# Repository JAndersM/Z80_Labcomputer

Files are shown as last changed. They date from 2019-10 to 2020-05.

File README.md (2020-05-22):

# Z80_Labcomputer

A computerproject based on the Z80 CPU.

## Dator
Motherboard with Z80, 8 kB ROM and 32 kB SRAM, IO ports, Bus ports etc.
* Schema, PCB designed
* Produced and tested. OK so far...

## cpukontroll
Clock, Reset etc.
* Schema, PCB design

## display
7x4-segment display and IO-connections to adress 0-3
* Schema PCB design

## tangentbord
Hex values input keyboard
* Schema, PCB design
Needs redesign

## EEPROMprogrammer
Arduino code and design for an Arduino Nano (or similar) based EEPROMprogrammer
* Schema, PCB design
Connected to the computer using BUSRQ to facilitate programming without removing ROM.

## simulering
Python simulation of the z80 cpu and the computer
* Inkludes 7x4 display
Many opcodes not simulated yet

## fastplatta
Holder for the Dator PCB
* 3D printed and tested

## Used software:
KiCad, FreeCAD, Python, Arduino IDE

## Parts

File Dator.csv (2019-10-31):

Reference | Quantity | Value | Footprint | Datasheet | Comment
C2 C3 C5 C6 C7 C1 C8 | 7 | 47n | Capacitor_THT:C_Disc_D3.0mm_W1.6mm_P2.50mm | ~
C4 | 1 | 22u | Capacitor_THT:C_Radial_D5.0mm_H11.0mm_P2.00mm | ~
D1 | 1 | LED | LED_THT:LED_D3.0mm | ~ | Green low current
H1 H2 | 2 | MountingHole | MountingHole:MountingHole_2.2mm_M2 | ~
J1 | 1 | CPU Control | Connector_PinHeader_2.54mm:PinHeader_1x05_P2.54mm_Vertical | ~
J2 | 1 | USB_B | Connector_USB:USB_B_OST_USB-B1HSxx_Horizontal | ~
J3 | 1 | IO Port | Connector_PinHeader_2.54mm:PinHeader_1x24_P2.54mm_Vertical | ~
J4 | 1 | Add Sig | Connector_PinSocket_2.54mm:PinSocket_1x05_P2.54mm_Vertical | ~
J5 | 1 | Address Bus | Connector_PinSocket_2.54mm:PinSocket_1x16_P2.54mm_Vertical | ~
J6 | 1 | Data Bus | Connector_PinSocket_2.54mm:PinSocket_1x08_P2.54mm_Vertical | ~
J7 | 1 | BUS NMI | Connector_PinSocket_2.54mm:PinSocket_1x05_P2.54mm_Vertical | ~
R1 | 1 | 1k5 | Resistor_THT:R_Axial_DIN0207_L6.3mm_D2.5mm_P7.62mm_Horizontal | ~
R2 R3 | 2 | 10k | Resistor_THT:R_Axial_DIN0207_L6.3mm_D2.5mm_P7.62mm_Horizontal | ~
U1 | 1 | 4002 | Package_DIP:DIP-14_W7.62mm | http://www.intersil.com/content/dam/Intersil/documents/cd40/cd4000bms-01bms-02bms-25bms.pdf
U2 U8 | 2 | 4071 | Package_DIP:DIP-14_W7.62mm | http://www.intersil.com/content/dam/Intersil/documents/cd40/cd4071bms-72bms-75bms.pdf
U3 | 1 | Z80CPU | Package_DIP:DIP-40_W15.24mm_Socket | www.zilog.com/manage_directlink.php?filepath=docs/z80/um0080
U4 | 1 | 74LS283 | Package_DIP:DIP-16_W7.62mm | http://www.ti.com/lit/gpn/sn74LS283
U5 | 1 | AT28C64B15PU | Package_DIP:DIP-28_W15.24mm_Socket
U6 | 1 | HM62256LP-8 | Package_DIP:DIP-28_W15.24mm_Socket
U7 | 1 | 74HC245 | Package_DIP:DIP-20_W7.62mm | http://www.ti.com/lit/gpn/sn74HC245

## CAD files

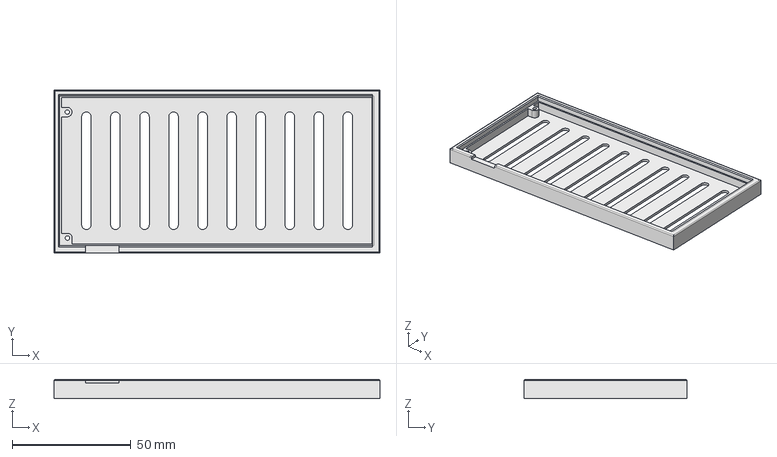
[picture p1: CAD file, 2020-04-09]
fastplatta/platta.FCStd
137.2 x 68.6 x 8.00 mm

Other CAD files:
fastplatta/platta.stl

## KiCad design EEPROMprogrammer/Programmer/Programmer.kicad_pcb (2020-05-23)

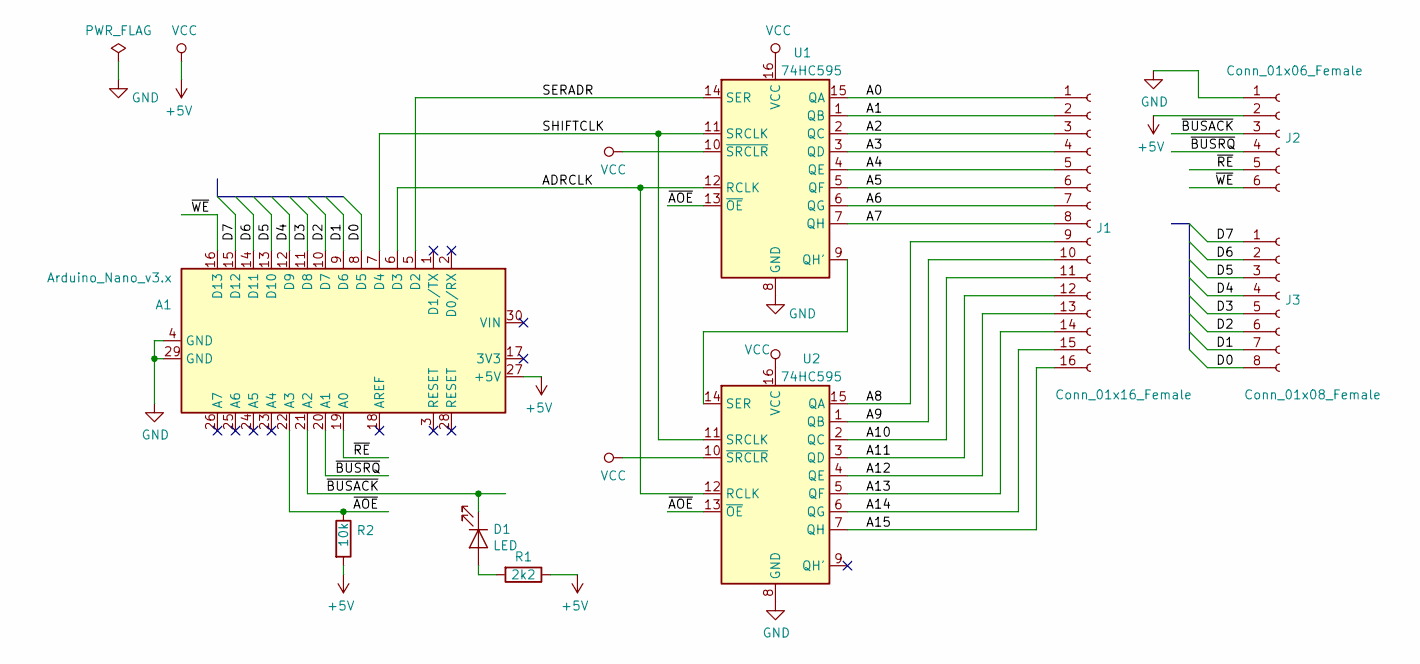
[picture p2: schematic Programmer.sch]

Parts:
A1: Arduino_Nano_v3.x; Arduino_Nano
D1: LED; LED_D3.0mm
J1: Conn_01x16_Female; PinSocket_1x16_P2.54mm_Vertical
J2: Conn_01x06_Female; PinSocket_1x06_P2.54mm_Vertical
J3: Conn_01x08_Female; PinSocket_1x08_P2.54mm_Vertical
R1: 2k2; R_Axial_DIN0207_L6.3mm_D2.5mm_P7.62mm_Horizontal
R2: 10k; R_Axial_DIN0207_L6.3mm_D2.5mm_P7.62mm_Horizontal
U1, U2: 74HC595; DIP-16_W7.62mm

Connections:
+5V: A1.27 (+5V), J2.2, R1.1, R2.2, U1.10 (~SRCLR), U1.16 (VCC), U2.10 (~SRCLR), U2.16 (VCC)
/A0: J1.1, U1.15 (QA)
/A1: J1.2, U1.1 (QB)
/A2: J1.3, U1.2 (QC)
/A3: J1.4, U1.3 (QD)
/A4: J1.5, U1.4 (QE)
/A5: J1.6, U1.5 (QF)
/A6: J1.7, U1.6 (QG)
/A7: J1.8, U1.7 (QH)
/A8: J1.9, U2.15 (QA)
/A9: J1.10, U2.1 (QB)
/A10: J1.11, U2.2 (QC)
/A11: J1.12, U2.3 (QD)
/A12: J1.13, U2.4 (QE)
/A13: J1.14, U2.5 (QF)
/A14: J1.15, U2.6 (QG)
/A15: J1.16, U2.7 (QH)
/ADRCLK: A1.6 (D3), U1.12 (RCLK), U2.12 (RCLK)
/D0: A1.8 (D5), J3.8
/D1: A1.9 (D6), J3.7
/D2: A1.10 (D7), J3.6
/D3: A1.11 (D8), J3.5
/D4: A1.12 (D9), J3.4
/D5: A1.13 (D10), J3.3
/D6: A1.14 (D11), J3.2
/D7: A1.15 (D12), J3.1
/SERADR: A1.5 (D2), U1.14 (SER)
/SHIFTCLK: A1.7 (D4), U1.11 (SRCLK), U2.11 (SRCLK)
/~AOE: A1.22 (A3), R2.1, U1.13 (~OE), U2.13 (~OE)
/~BUSACK: A1.21 (A2), D1.1 (K), J2.3
/~BUSRQ: A1.20 (A1), J2.4
/~RE: A1.19 (A0), J2.5
/~WE: A1.16 (D13), J2.6
GND: A1.4 (GND), A1.29 (GND), J2.1, U1.8 (GND), U2.8 (GND)
unnamed: D1.2 (A), R1.2
unnamed: U1.9 (QH'), U2.14 (SER)

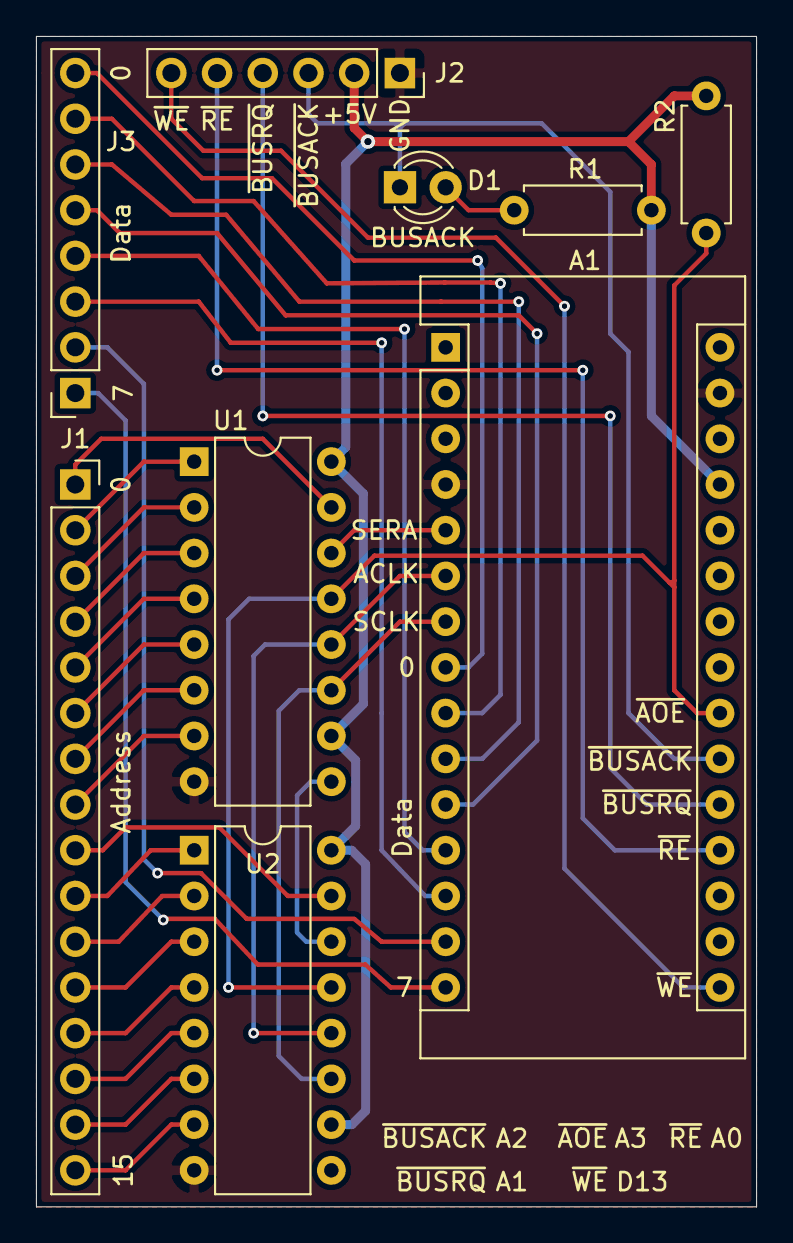
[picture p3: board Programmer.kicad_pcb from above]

Board: 2 copper layers, 40.0 x 65.0 mm, 9 parts (0 on the bottom side), 36 nets.

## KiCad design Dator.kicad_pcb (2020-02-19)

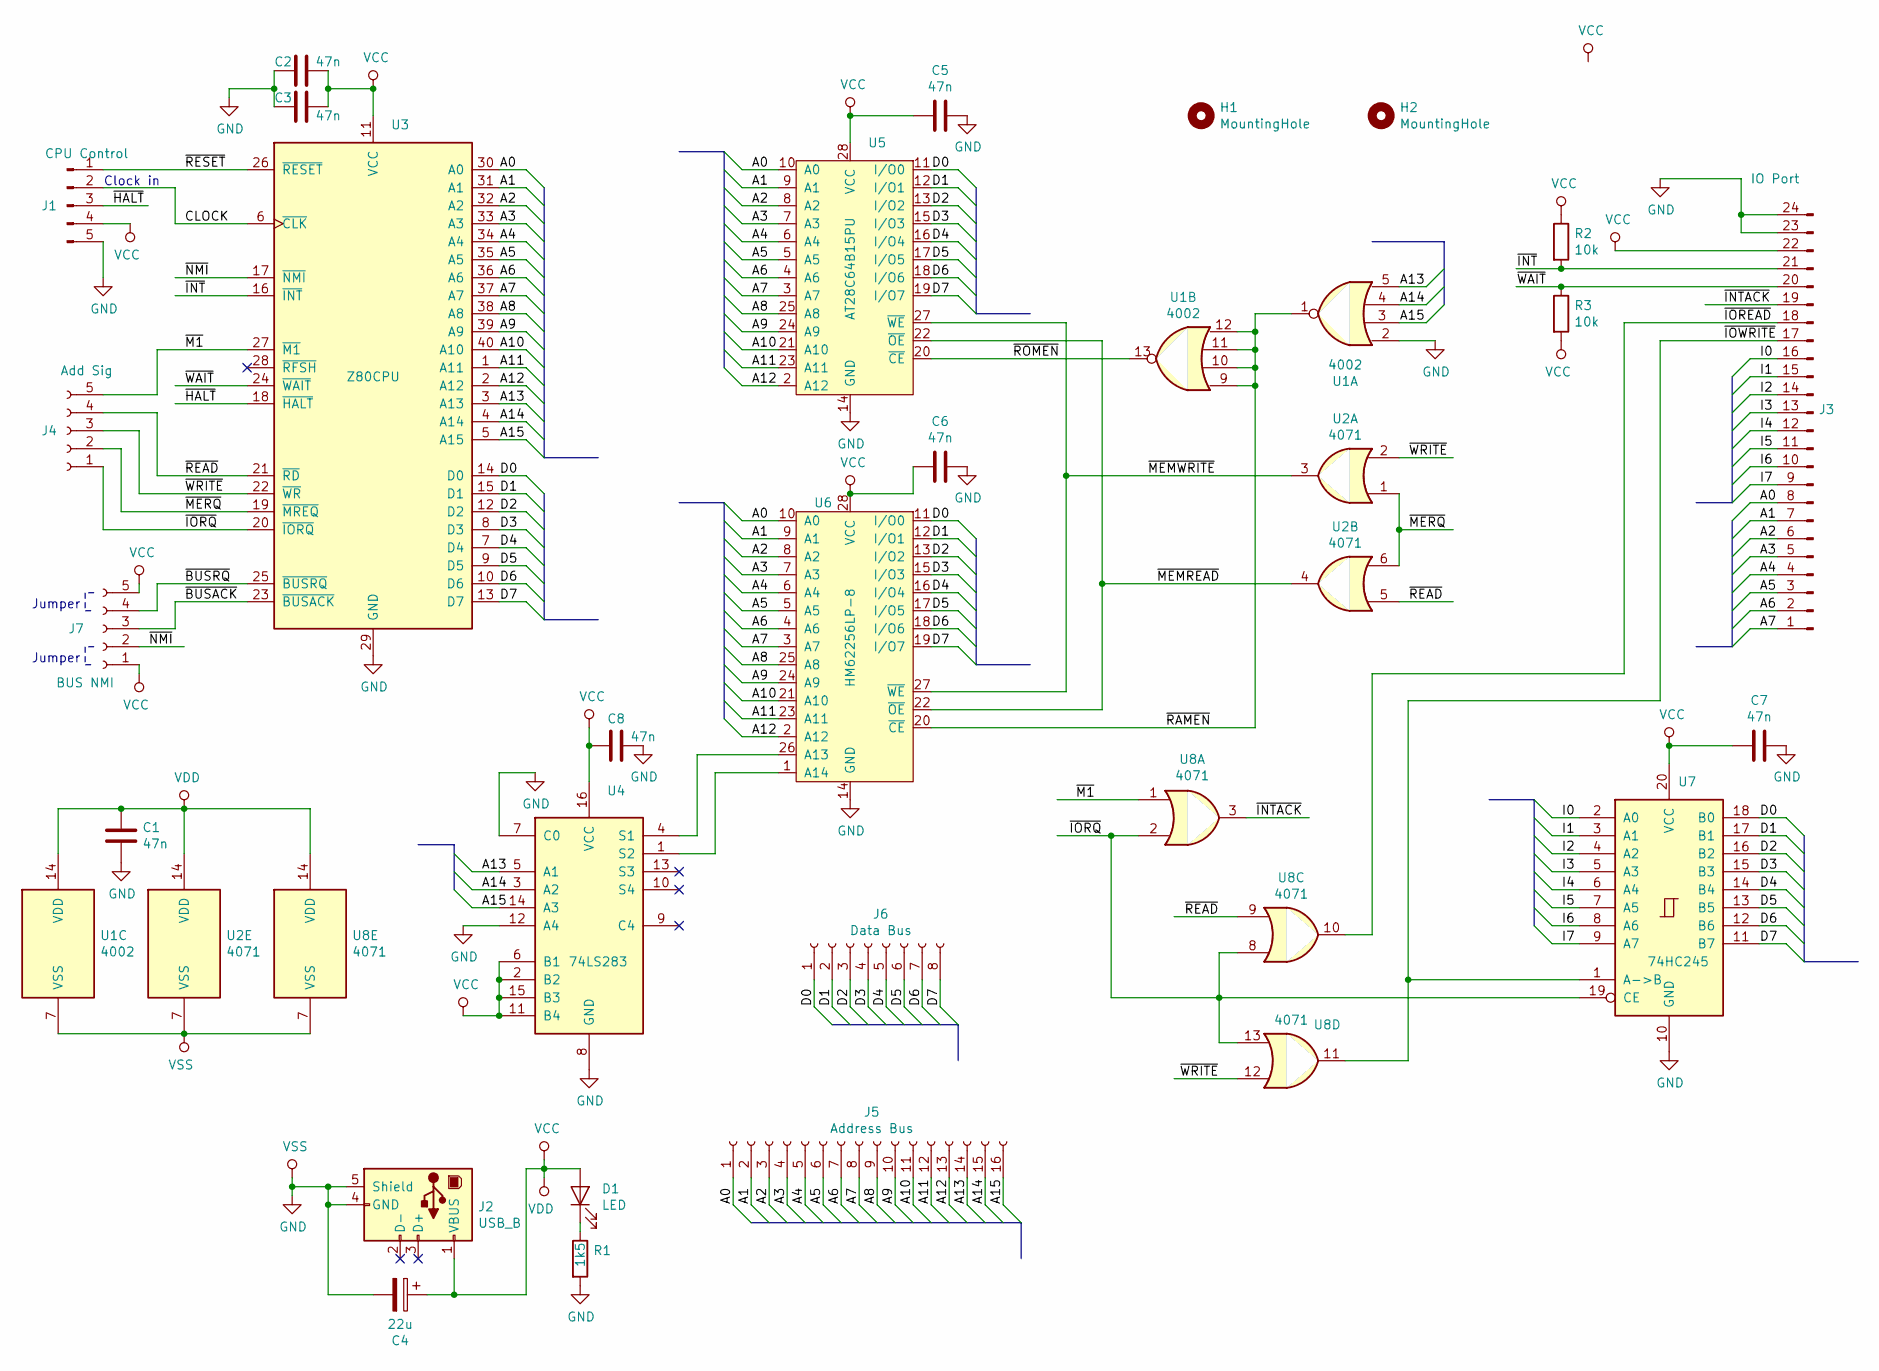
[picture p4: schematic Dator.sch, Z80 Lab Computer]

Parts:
C1, C2, C3, C5, C6, C7, C8: 47n; C_Disc_D3.0mm_W1.6mm_P2.50mm
C4: 22u; C_Radial_D5.0mm_H11.0mm_P2.00mm
D1: LED; LED_D3.0mm
H1, H2: MountingHole; MountingHole_2.2mm_M2
J1: CPU Control; PinHeader_1x05_P2.54mm_Vertical
J2: USB_B; USB_B_OST_USB-B1HSxx_Horizontal
J3: IO Port; PinHeader_1x24_P2.54mm_Vertical
J4: Add Sig; PinSocket_1x05_P2.54mm_Vertical
J5: Address Bus; PinSocket_1x16_P2.54mm_Vertical
J6: Data Bus; PinSocket_1x08_P2.54mm_Vertical
J7: BUS NMI; PinSocket_1x05_P2.54mm_Vertical
R1: 1k5; R_Axial_DIN0207_L6.3mm_D2.5mm_P7.62mm_Horizontal
R2, R3: 10k; R_Axial_DIN0207_L6.3mm_D2.5mm_P7.62mm_Horizontal
U1: 4002; DIP-14_W7.62mm
U2, U8: 4071; DIP-14_W7.62mm
U3: Z80CPU; DIP-40_W15.24mm_Socket
U4: 74LS283; DIP-16_W7.62mm
U5: AT28C64B15PU; DIP-28_W15.24mm_Socket
U6: HM62256LP-8; DIP-28_W15.24mm_Socket
U7: 74HC245; DIP-20_W7.62mm

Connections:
/A0: J3.8, J5.1, U3.30 (A0), U5.10 (A0), U6.10 (A0)
/A1: J3.7, J5.2, U3.31 (A1), U5.9 (A1), U6.9 (A1)
/A2: J3.6, J5.3, U3.32 (A2), U5.8 (A2), U6.8 (A2)
/A3: J3.5, J5.4, U3.33 (A3), U5.7 (A3), U6.7 (A3)
/A4: J3.4, J5.5, U3.34 (A4), U5.6 (A4), U6.6 (A4)
/A5: J3.3, J5.6, U3.35 (A5), U5.5 (A5), U6.5 (A5)
/A6: J3.2, J5.7, U3.36 (A6), U5.4 (A6), U6.4 (A6)
/A7: J3.1, J5.8, U3.37 (A7), U5.3 (A7), U6.3 (A7)
/A8: J5.9, U3.38 (A8), U5.25 (A8), U6.25 (A8)
/A9: J5.10, U3.39 (A9), U5.24 (A9), U6.24 (A9)
/A10: J5.11, U3.40 (A10), U5.21 (A10), U6.21 (A10)
/A11: J5.12, U3.1 (A11), U5.23 (A11), U6.23 (A11)
/A12: J5.13, U3.2 (A12), U5.2 (A12), U6.2 (A12)
/A13: J5.14, U1.5, U3.3 (A13), U4.5 (A1)
/A14: J5.15, U1.4, U3.4 (A14), U4.3 (A2)
/A15: J5.16, U1.3, U3.5 (A15), U4.14 (A3)
/CLOCK: J1.2, U3.6 (~CLK~)
/D0: J6.1, U3.14 (D0), U5.11 (I/O0), U6.11 (I/O0), U7.18 (B0)
/D1: J6.2, U3.15 (D1), U5.12 (I/O1), U6.12 (I/O1), U7.17 (B1)
/D2: J6.3, U3.12 (D2), U5.13 (I/O2), U6.13 (I/O2), U7.16 (B2)
/D3: J6.4, U3.8 (D3), U5.15 (I/O3), U6.15 (I/O3), U7.15 (B3)
/D4: J6.5, U3.7 (D4), U5.16 (I/O4), U6.16 (I/O4), U7.14 (B4)
/D5: J6.6, U3.9 (D5), U5.17 (I/O5), U6.17 (I/O5), U7.13 (B5)
/D6: J6.7, U3.10 (D6), U5.18 (I/O6), U6.18 (I/O6), U7.12 (B6)
/D7: J6.8, U3.13 (D7), U5.19 (I/O7), U6.19 (I/O7), U7.11 (B7)
/I0: J3.16, U7.2 (A0)
/I1: J3.15, U7.3 (A1)
/I2: J3.14, U7.4 (A2)
/I3: J3.13, U7.5 (A3)
/I4: J3.12, U7.6 (A4)
/I5: J3.11, U7.7 (A5)
/I6: J3.10, U7.8 (A6)
/I7: J3.9, U7.9 (A7)
/~BUSACK: J7.3, U3.23 (~BUSACK~)
/~BUSRQ: J7.4, U3.25 (~BUSRQ~)
/~HALT: J1.3, U3.18 (~HALT~)
/~INT: J3.21, R2.2, U3.16 (~INT~)
/~INTACK: J3.19, U8.3
/~IOREAD: J3.18, U8.10
/~IORQ: J4.1, U3.20 (~IORQ~), U7.19 (CE), U8.2, U8.8, U8.13
/~IOWRITE: J3.17, U7.1 (A->B), U8.11
/~M1: J4.5, U3.27 (~M1~), U8.1
/~MEMREAD: U2.4, U5.22 (~OE), U6.22 (~OE)
/~MEMWRITE: U2.3, U5.27 (~WE), U6.27 (~WE)
/~MERQ: J4.2, U2.1, U2.6, U3.19 (~MREQ~)
/~NMI: J7.2, U3.17 (~NMI~)
/~RAMEN: U1.1, U1.9, U1.10, U1.11, U1.12, U6.20 (~CE)
/~READ: J4.4, U2.5, U3.21 (~RD~), U8.9
/~RESET: J1.1, U3.26 (~RESET~)
/~ROMEN: U1.13, U5.20 (~CE)
/~WAIT: J3.20, R3.1, U3.24 (~WAIT~)
/~WRITE: J4.3, U2.2, U3.22 (~WR~), U8.12
GND: C1.2, C2.2, C3.2, C4.2, C5.1, C6.1, C7.1, C8.1, J1.5, J2.4 (GND), J2.5 (Shield), J3.23, J3.24, R1.2, U1.2, U1.7 (VSS), U2.7 (VSS), U3.29 (GND), U4.7 (C0), U4.8 (GND), U4.12 (A4), U5.14 (GND), U6.14 (GND), U7.10 (GND), U8.7 (VSS)
unnamed: D1.1 (K), R1.1
unnamed: U4.1 (S2), U6.1 (A14)
unnamed: U4.4 (S1), U6.26 (A13)
VCC: C1.1, C2.1, C3.1, C4.1, C5.2, C6.2, C7.2, C8.2, D1.2 (A), J1.4, J2.1 (VBUS), J3.22, J7.1, J7.5, R2.1, R3.2, U1.14 (VDD), U2.14 (VDD), U3.11 (VCC), U4.2 (B2), U4.6 (B1), U4.11 (B4), U4.15 (B3), U4.16 (VCC), U5.28 (VCC), U6.28 (VCC), U7.20 (VCC), U8.14 (VDD)

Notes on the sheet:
Clock in
Jumper

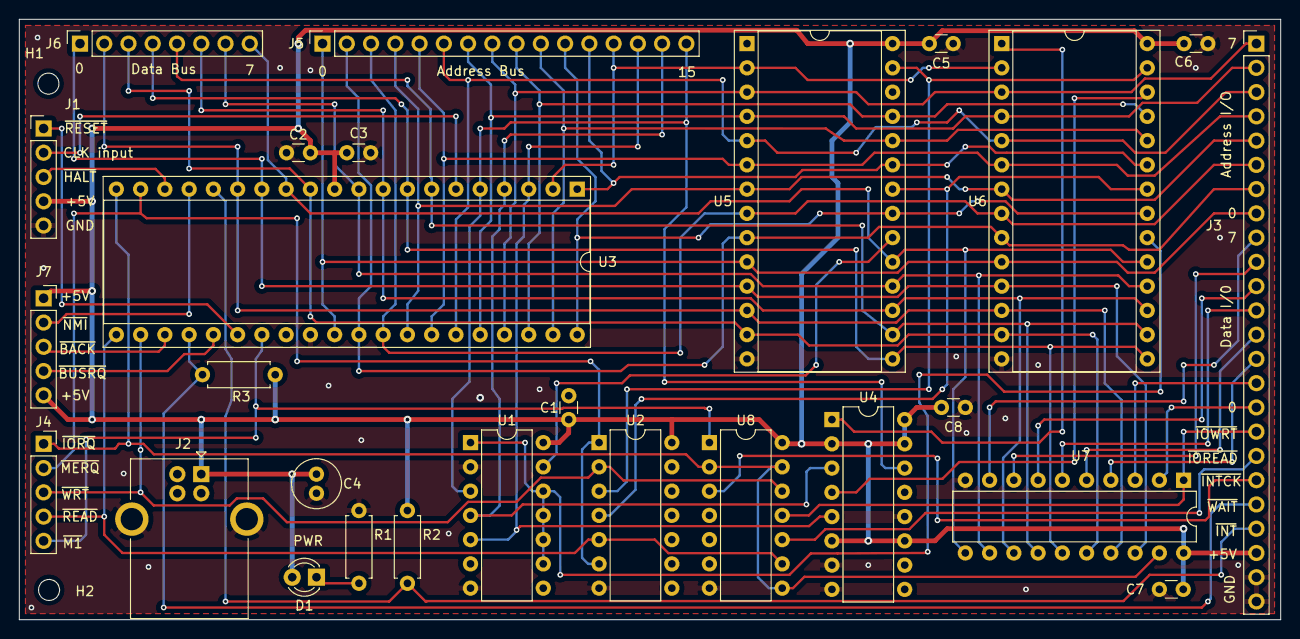
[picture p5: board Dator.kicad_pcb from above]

Board: 2 copper layers, 132.1 x 62.9 mm, 29 parts (0 on the bottom side), 57 nets.

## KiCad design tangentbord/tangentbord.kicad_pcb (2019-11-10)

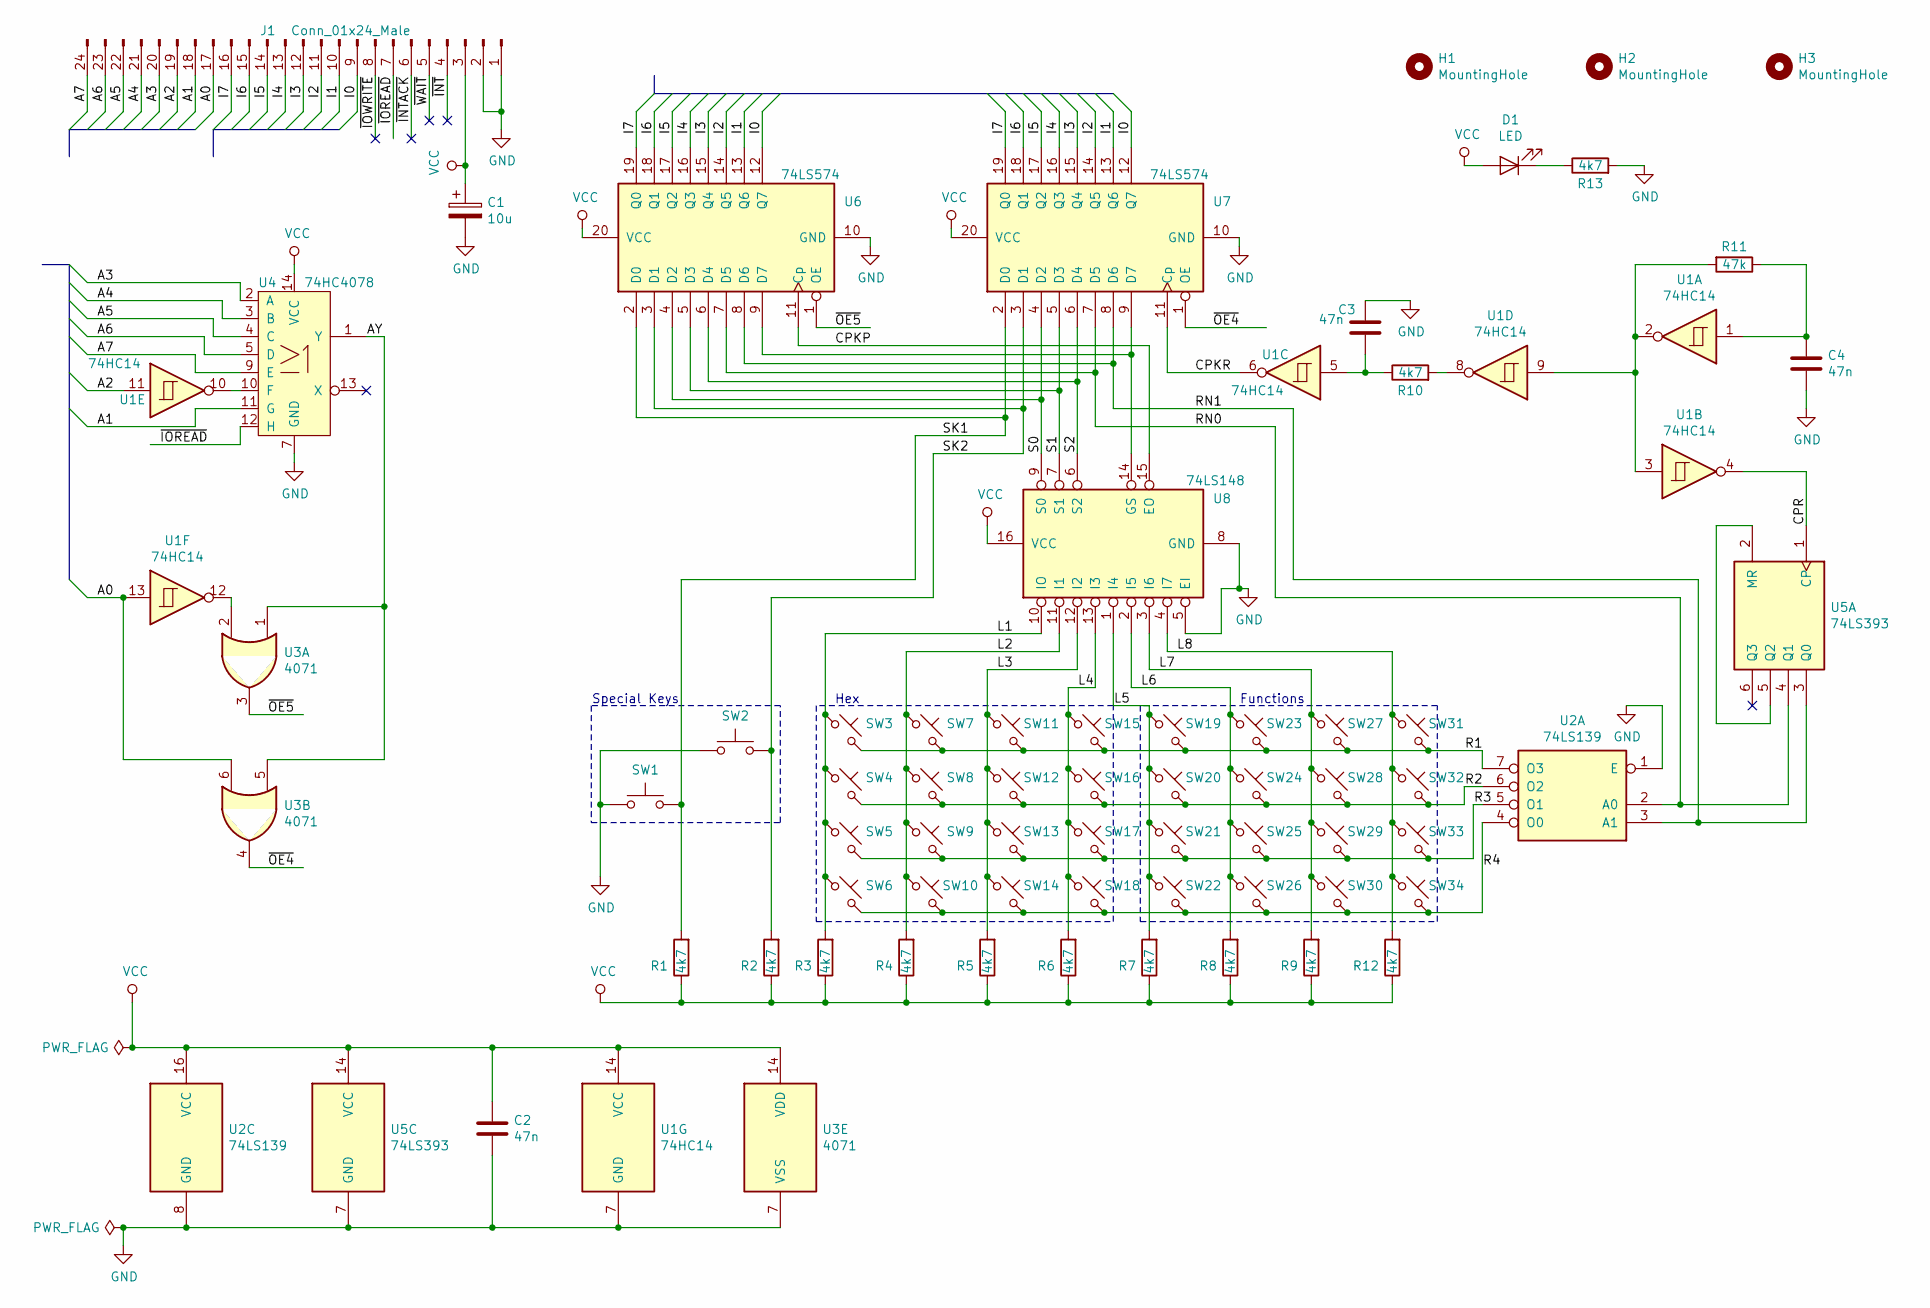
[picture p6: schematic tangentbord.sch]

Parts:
C1: 10u; CP_Radial_D5.0mm_P2.00mm
C2, C3, C4: 47n; C_Disc_D3.0mm_W2.0mm_P2.50mm
D1: LED; LED_D3.0mm
H1, H2, H3: MountingHole; MountingHole_2.2mm_M2
J1: Conn_01x24_Male; PinHeader_1x24_P2.54mm_Vertical
R1, R2, R3, R4, R5, R6, R7, R8, R9, R10, R12, R13: 4k7; R_Axial_DIN0207_L6.3mm_D2.5mm_P7.62mm_Horizontal
R11: 47k; R_Axial_DIN0207_L6.3mm_D2.5mm_P7.62mm_Horizontal
SW1, SW2: SW_Push; SW_PUSH_6mm
SW3, SW4, SW5, SW6, SW7, SW8, SW9, SW10, SW11, SW12, SW13, SW14, SW15, SW16, SW17, SW18, SW19, SW20, SW21, SW22, SW23, SW24, SW25, SW26, SW27, SW28, SW29, SW30, SW31, SW32, SW33, SW34: SW_Push_45deg; SW_PUSH_6mm
U1: 74HC14; DIP-14_W7.62mm
U2: 74LS139; DIP-16_W7.62mm
U3: 4071; DIP-14_W7.62mm
U4: 74HC4078; DIP-14_W7.62mm
U5: 74LS393; DIP-14_W7.62mm
U6, U7: 74LS574; DIP-20_W7.62mm
U8: 74LS148; DIP-16_W7.62mm

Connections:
/A0: J1.17, U1.13, U3.6
/A1: J1.18, U4.11 (G)
/A2: J1.19, U1.11
/A3: J1.20, U4.2 (A)
/A4: J1.21, U4.3 (B)
/A5: J1.22, U4.4 (C)
/A6: J1.23, U4.5 (D)
/A7: J1.24, U4.9 (E)
/AY: U3.1, U3.5, U4.1 (Y)
/CPKP: U6.11 (Cp), U8.15 (EO)
/CPKR: U1.6, U7.11 (Cp)
/CPR: U1.4, U5.1 (CP)
/I0: J1.9, U6.12 (Q7), U7.12 (Q7)
/I1: J1.10, U6.13 (Q6), U7.13 (Q6)
/I2: J1.11, U6.14 (Q5), U7.14 (Q5)
/I3: J1.12, U6.15 (Q4), U7.15 (Q4)
/I4: J1.13, U6.16 (Q3), U7.16 (Q3)
/I5: J1.14, U6.17 (Q2), U7.17 (Q2)
/I6: J1.15, U6.18 (Q1), U7.18 (Q1)
/I7: J1.16, U6.19 (Q0), U7.19 (Q0)
/L1: R3.2, SW3.1, SW4.1, SW5.1, SW6.1, U8.10 (IO)
/L2: R4.2, SW7.1, SW8.1, SW9.1, SW10.1, U8.11 (I1)
/L3: R5.2, SW11.1, SW12.1, SW13.1, SW14.1, U8.12 (I2)
/L4: R6.2, SW15.1, SW16.1, SW17.1, SW18.1, U8.13 (I3)
/L5: R7.2, SW19.1, SW20.1, SW21.1, SW22.1, U8.1 (I4)
/L6: R8.2, SW23.1, SW24.1, SW25.1, SW26.1, U8.2 (I5)
/L7: R9.2, SW27.1, SW28.1, SW29.1, SW30.1, U8.3 (I6)
/L8: R12.2, SW31.1, SW32.1, SW33.1, SW34.1, U8.4 (I7)
/R1: SW3.2, SW7.2, SW11.2, SW15.2, SW19.2, SW23.2, SW27.2, SW31.2, U2.7 (O3)
/R2: SW4.2, SW8.2, SW12.2, SW16.2, SW20.2, SW24.2, SW28.2, SW32.2, U2.6 (O2)
/R3: SW5.2, SW9.2, SW13.2, SW17.2, SW21.2, SW25.2, SW29.2, SW33.2, U2.5 (O1)
/R4: SW6.2, SW10.2, SW14.2, SW18.2, SW22.2, SW26.2, SW30.2, SW34.2, U2.4 (O0)
/RN0: U2.2 (A0), U5.4 (Q1), U6.7 (D5), U7.7 (D5)
/RN1: U2.3 (A1), U5.3 (Q0), U6.8 (D6), U7.8 (D6)
/S0: U6.4 (D2), U7.4 (D2), U8.9 (S0)
/S1: U6.5 (D3), U7.5 (D3), U8.7 (S1)
/S2: U6.6 (D4), U7.6 (D4), U8.6 (S2)
/SK1: R1.2, SW1.2, U6.2 (D0), U7.2 (D0)
/SK2: R2.2, SW2.2, U6.3 (D1), U7.3 (D1)
/~INT: J1.4
/~INTACK: J1.6
/~IOREAD: J1.7, U4.12 (H)
/~IOWRITE: J1.8
/~OE4: U3.4, U7.1 (OE)
/~OE5: U3.3, U6.1 (OE)
/~WAIT: J1.5
GND: C1.2, C2.2, C3.2, C4.2, J1.1, J1.2, R13.2, SW1.1, SW2.1, U1.7 (GND), U2.1 (E), U2.8 (GND), U3.7 (VSS), U4.7 (GND), U5.7 (GND), U6.10 (GND), U7.10 (GND), U8.5 (EI), U8.8 (GND)
unnamed: C3.1, R10.1, U1.5
unnamed: C4.1, R11.1, U1.1
unnamed: D1.1 (K), R13.1
unnamed: R10.2, U1.8
unnamed: R11.2, U1.2, U1.3, U1.9
unnamed: U1.10, U4.10 (F)
unnamed: U1.12, U3.2
unnamed: U5.2 (MR), U5.5 (Q2)
unnamed: U6.9 (D7), U7.9 (D7), U8.14 (GS)
VCC: C1.1, C2.1, D1.2 (A), J1.3, R1.1, R2.1, R3.1, R4.1, R5.1, R6.1, R7.1, R8.1, R9.1, R12.1, U1.14 (VCC), U2.16 (VCC), U3.14 (VDD), U4.14 (VCC), U5.14 (VCC), U6.20 (VCC), U7.20 (VCC), U8.16 (VCC)

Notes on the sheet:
Special Keys
Hex
Functions

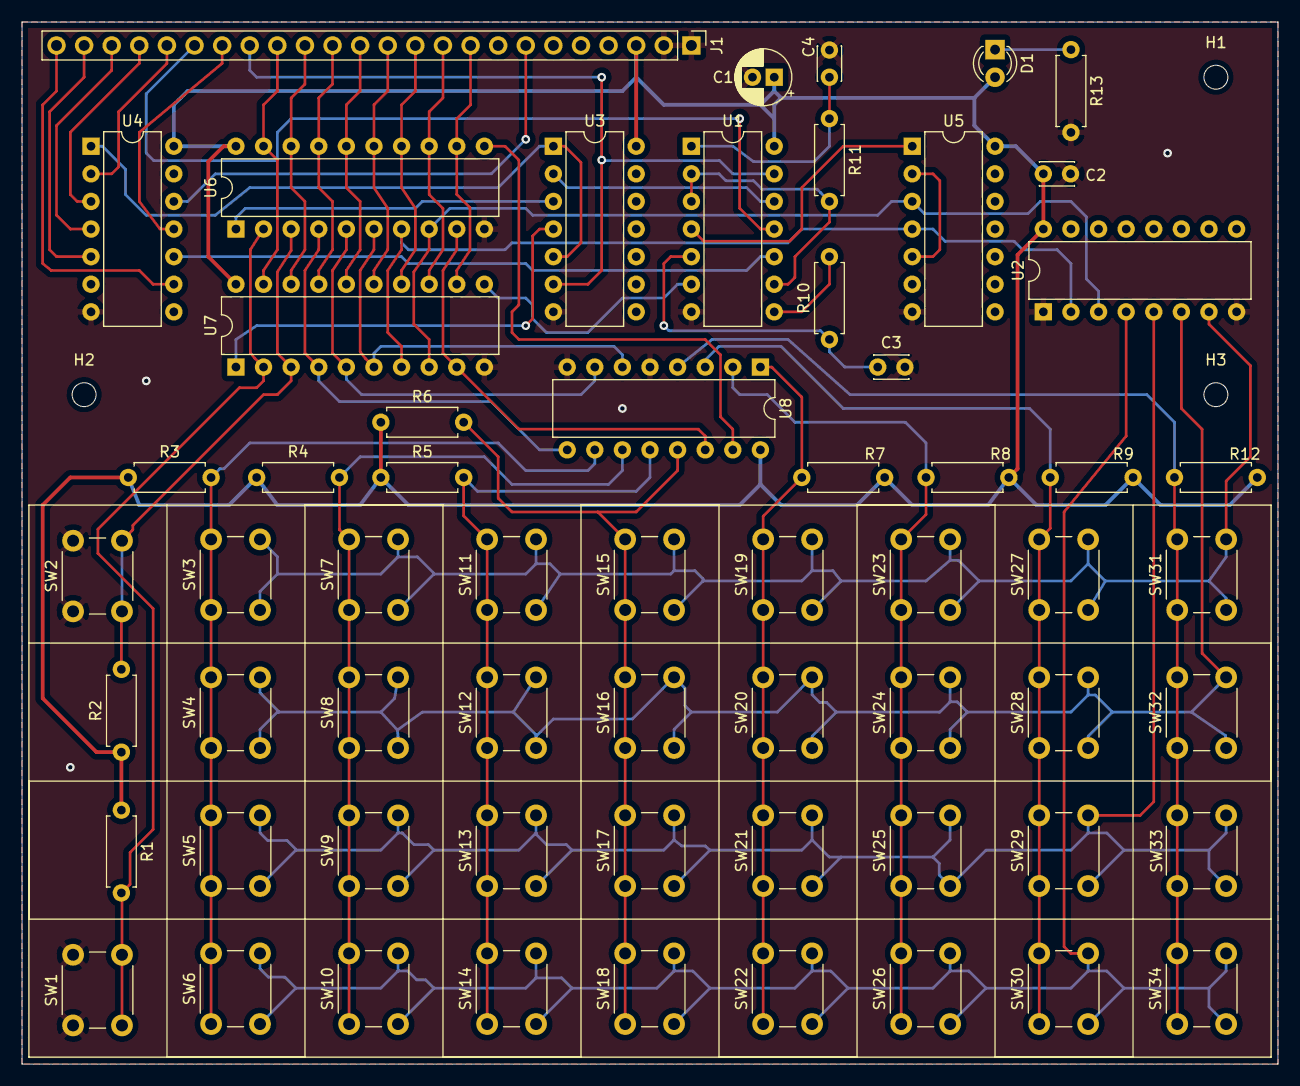
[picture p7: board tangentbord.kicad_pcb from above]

Board: 2 copper layers, 115.6 x 95.9 mm, 64 parts (0 on the bottom side), 53 nets.

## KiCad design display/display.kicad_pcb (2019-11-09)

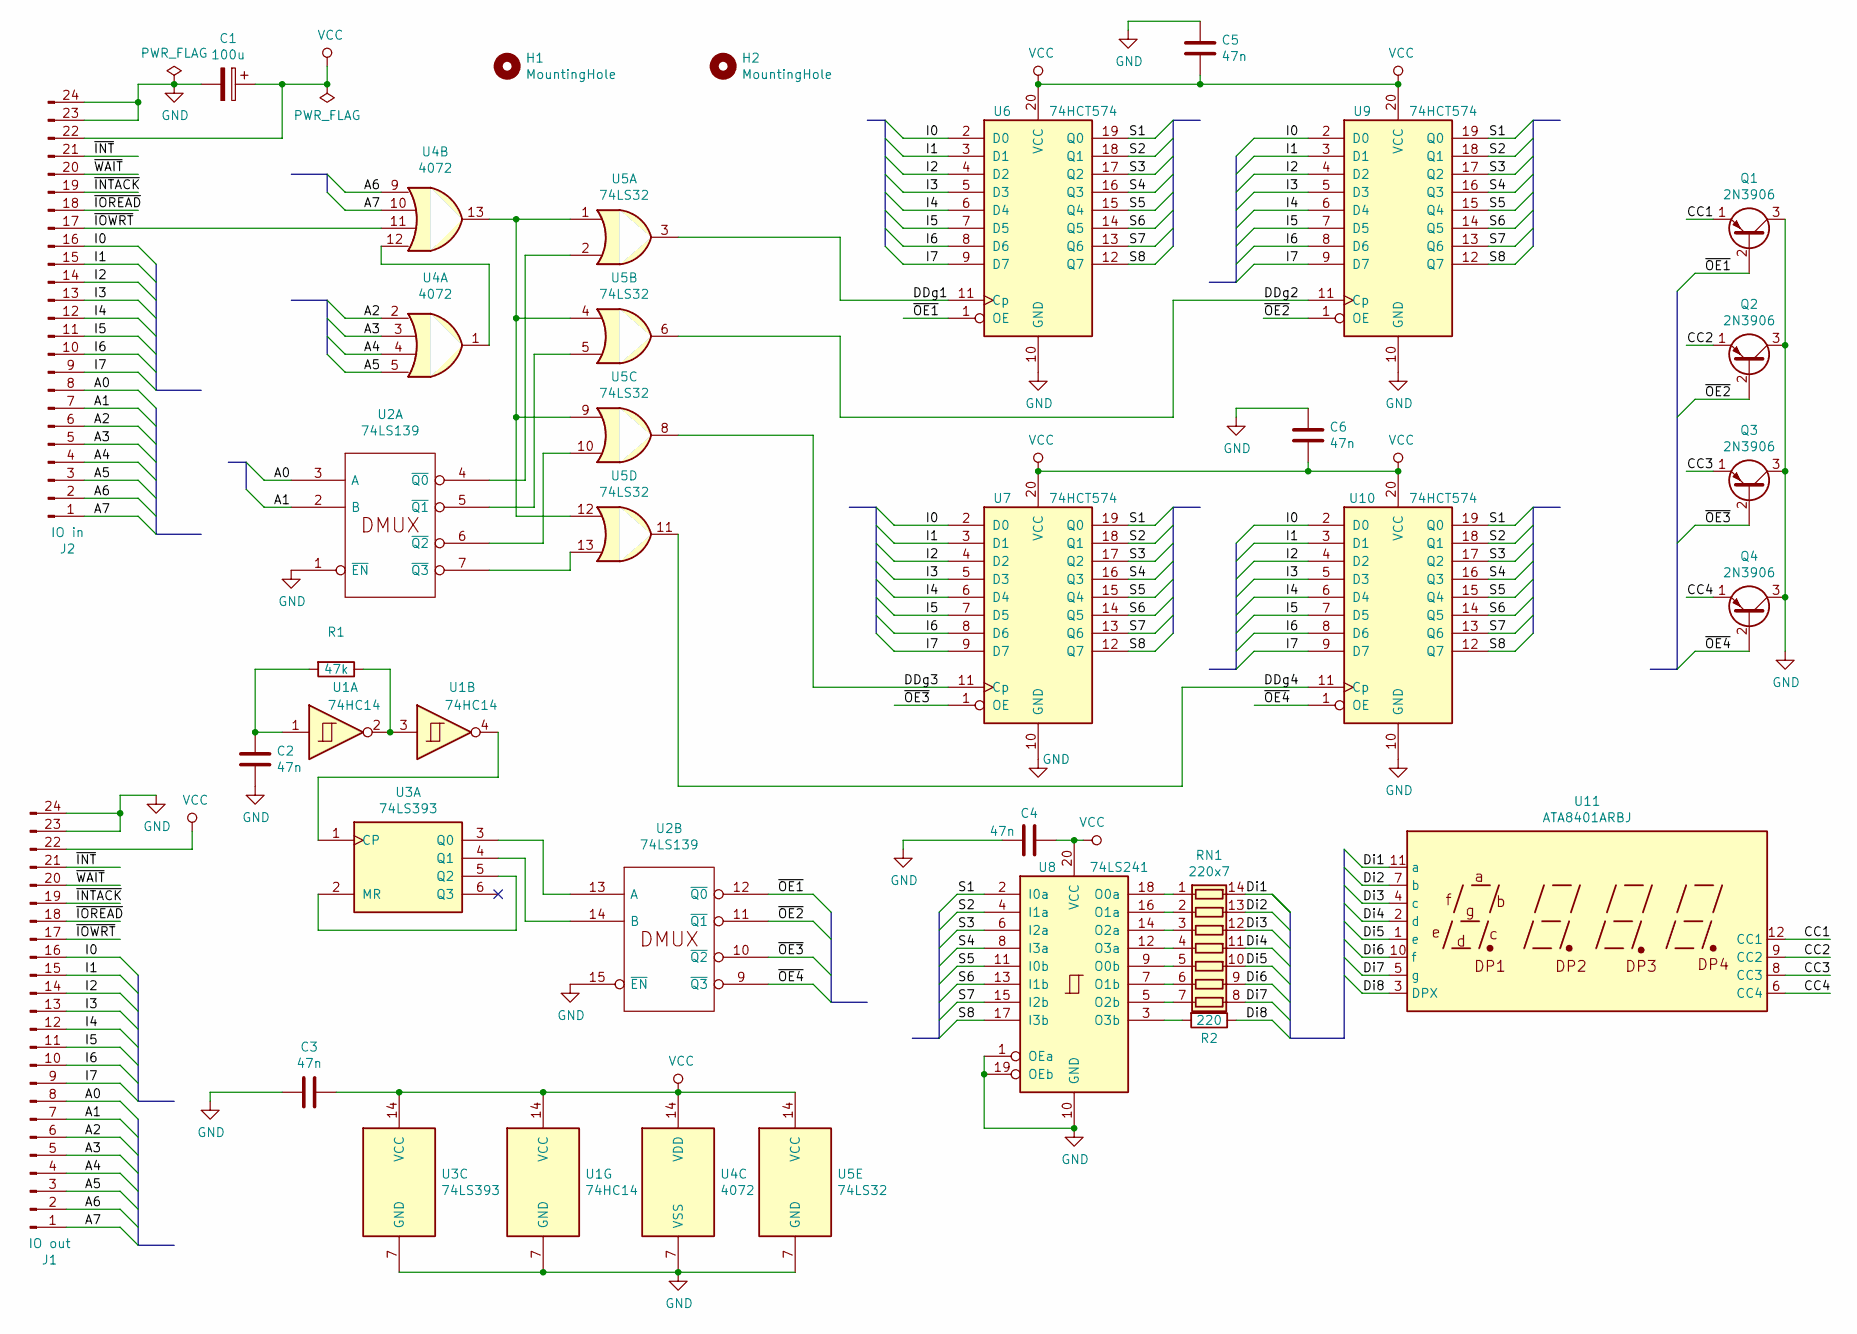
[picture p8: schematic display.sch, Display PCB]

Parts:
C1: 100u; CP_Radial_D6.3mm_P2.50mm
C2, C3, C4, C5, C6: 47n; C_Disc_D3.0mm_W1.6mm_P2.50mm
H1, H2: MountingHole; MountingHole_2.2mm_M2
J1: IO out; PinHeader_1x24_P2.54mm_Vertical
J2: IO in; PinHeader_1x24_P2.54mm_Vertical
Q1, Q2, Q3, Q4: 2N3906; TO-92L_Inline_Wide
R1: 47k; R_Axial_DIN0207_L6.3mm_D2.5mm_P7.62mm_Horizontal
R2: 220; R_Axial_DIN0207_L6.3mm_D2.5mm_P7.62mm_Horizontal
RN1: 220x7; DIP-14_W7.62mm
U1: 74HC14; DIP-14_W7.62mm
U2: 74LS139; DIP-16_W7.62mm
U3: 74LS393; DIP-14_W7.62mm
U4: 4072; DIP-14_W7.62mm
U5: 74LS32; DIP-14_W7.62mm
U6, U7, U9, U10: 74HCT574; DIP-20_W7.62mm
U8: 74LS241; DIP-20_W7.62mm
U11: ATA8401ARBJ

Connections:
/A0: J1.8, J2.8, U2.3 (A)
/A1: J1.7, J2.7, U2.2 (B)
/A2: J1.6, J2.6, U4.2
/A3: J1.5, J2.5, U4.3
/A4: J1.4, J2.4, U4.4
/A5: J1.3, J2.3, U4.5
/A6: J1.2, J2.2, U4.9
/A7: J1.1, J2.1, U4.10
/CC1: Q1.1 (E), U11.12 (CC1)
/CC2: Q2.1 (E), U11.9 (CC2)
/CC3: Q3.1 (E), U11.8 (CC3)
/CC4: Q4.1 (E), U11.6 (CC4)
/DDg1: U5.3, U6.11 (Cp)
/DDg2: U5.6, U9.11 (Cp)
/DDg3: U5.8, U7.11 (Cp)
/DDg4: U5.11, U10.11 (Cp)
/Di1: RN1.14 (R1.2), U11.11 (a)
/Di2: RN1.13 (R2.2), U11.7 (b)
/Di3: RN1.12 (R3.2), U11.4 (c)
/Di4: RN1.11 (R4.2), U11.2 (d)
/Di5: RN1.10 (R5.2), U11.1 (e)
/Di6: RN1.9 (R6.2), U11.10 (f)
/Di7: RN1.8 (R7.2), U11.5 (g)
/Di8: R2.1, U11.3 (DPX)
/I0: J1.16, J2.16, U6.2 (D0), U7.2 (D0), U9.2 (D0), U10.2 (D0)
/I1: J1.15, J2.15, U6.3 (D1), U7.3 (D1), U9.3 (D1), U10.3 (D1)
/I2: J1.14, J2.14, U6.4 (D2), U7.4 (D2), U9.4 (D2), U10.4 (D2)
/I3: J1.13, J2.13, U6.5 (D3), U7.5 (D3), U9.5 (D3), U10.5 (D3)
/I4: J1.12, J2.12, U6.6 (D4), U7.6 (D4), U9.6 (D4), U10.6 (D4)
/I5: J1.11, J2.11, U6.7 (D5), U7.7 (D5), U9.7 (D5), U10.7 (D5)
/I6: J1.10, J2.10, U6.8 (D6), U7.8 (D6), U9.8 (D6), U10.8 (D6)
/I7: J1.9, J2.9, U6.9 (D7), U7.9 (D7), U9.9 (D7), U10.9 (D7)
/S1: U6.19 (Q0), U7.19 (Q0), U8.2 (I0a), U9.19 (Q0), U10.19 (Q0)
/S2: U6.18 (Q1), U7.18 (Q1), U8.4 (I1a), U9.18 (Q1), U10.18 (Q1)
/S3: U6.17 (Q2), U7.17 (Q2), U8.6 (I2a), U9.17 (Q2), U10.17 (Q2)
/S4: U6.16 (Q3), U7.16 (Q3), U8.8 (I3a), U9.16 (Q3), U10.16 (Q3)
/S5: U6.15 (Q4), U7.15 (Q4), U8.11 (I0b), U9.15 (Q4), U10.15 (Q4)
/S6: U6.14 (Q5), U7.14 (Q5), U8.13 (I1b), U9.14 (Q5), U10.14 (Q5)
/S7: U6.13 (Q6), U7.13 (Q6), U8.15 (I2b), U9.13 (Q6), U10.13 (Q6)
/S8: U6.12 (Q7), U7.12 (Q7), U8.17 (I3b), U9.12 (Q7), U10.12 (Q7)
/~INT: J1.21, J2.21
/~INTACK: J1.19, J2.19
/~IOREAD: J1.18, J2.18
/~IOWRT: J1.17, J2.17, U4.11
/~OE1: Q1.2 (B), U2.12 (~Q0), U6.1 (OE)
/~OE2: Q2.2 (B), U2.11 (~Q1), U9.1 (OE)
/~OE3: Q3.2 (B), U2.10 (~Q2), U7.1 (OE)
/~OE4: Q4.2 (B), U2.9 (~Q3), U10.1 (OE)
/~WAIT: J1.20, J2.20
GND: C1.2, C2.1, C3.2, C4.2, C5.1, C6.1, J1.23, J1.24, J2.23, J2.24, Q1.3 (C), Q2.3 (C), Q3.3 (C), Q4.3 (C), U1.7 (GND), U2.1 (~EN), U2.8 (GND), U2.15 (~EN), U3.7 (GND), U4.7 (VSS), U5.7 (GND), U6.10 (GND), U7.10 (GND), U8.1 (OEa), U8.10 (GND), U8.19 (OEb), U9.10 (GND), U10.10 (GND)
unnamed: C2.2, R1.2, U1.1
unnamed: R1.1, U1.2, U1.3
unnamed: R2.2, U8.3 (O3b)
unnamed: RN1.1 (R1.1), U8.18 (O0a)
unnamed: RN1.2 (R2.1), U8.16 (O1a)
unnamed: RN1.3 (R3.1), U8.14 (O2a)
unnamed: RN1.4 (R4.1), U8.12 (O3a)
unnamed: RN1.5 (R5.1), U8.9 (O0b)
unnamed: RN1.6 (R6.1), U8.7 (O1b)
unnamed: RN1.7 (R7.1), U8.5 (O2b)
unnamed: U1.4, U3.1 (CP)
unnamed: U2.4 (~Q0), U5.2
unnamed: U2.5 (~Q1), U5.5
unnamed: U2.6 (~Q2), U5.10
unnamed: U2.7 (~Q3), U5.13
unnamed: U2.13 (A), U3.3 (Q0)
unnamed: U2.14 (B), U3.4 (Q1)
unnamed: U3.2 (MR), U3.5 (Q2)
unnamed: U4.1, U4.12
unnamed: U4.13, U5.1, U5.4, U5.9, U5.12
VCC: C1.1, C3.1, C4.1, C5.2, C6.2, J1.22, J2.22, U1.14 (VCC), U2.16 (VCC), U3.14 (VCC), U4.14 (VDD), U5.14 (VCC), U6.20 (VCC), U7.20 (VCC), U8.20 (VCC), U9.20 (VCC), U10.20 (VCC)

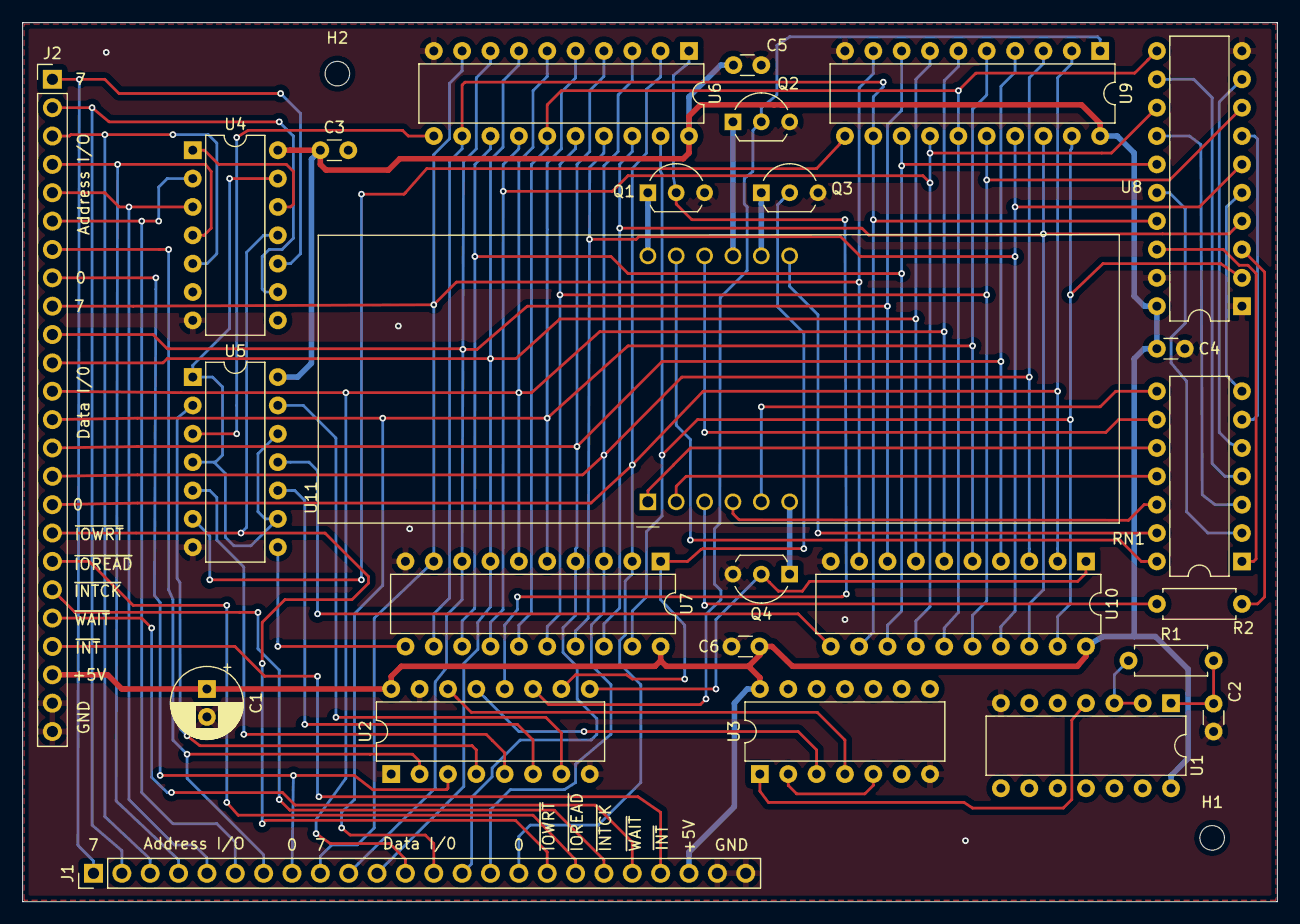
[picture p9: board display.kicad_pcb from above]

Board: 2 copper layers, 112.4 x 78.7 mm, 28 parts (0 on the bottom side), 71 nets.

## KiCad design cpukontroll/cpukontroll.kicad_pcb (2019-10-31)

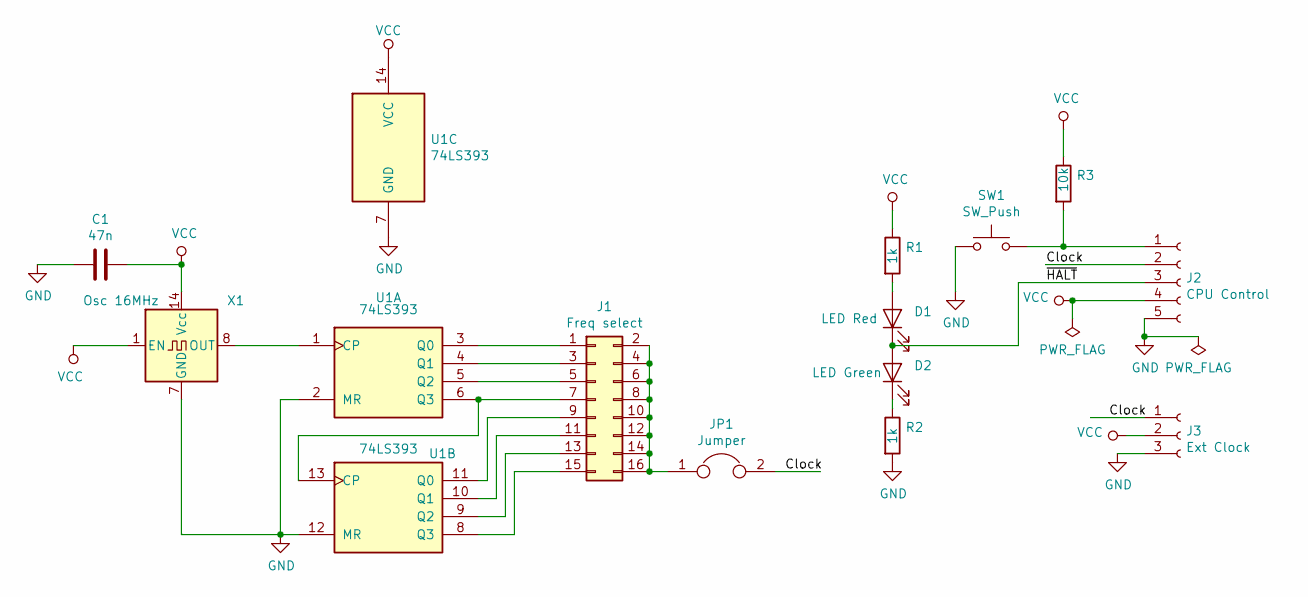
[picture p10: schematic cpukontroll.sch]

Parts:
C1: 47n; C_Disc_D3.0mm_W1.6mm_P2.50mm
D1: LED Red; LED_D3.0mm
D2: LED Green; LED_D3.0mm
J1: Freq select; PinSocket_2x08_P2.54mm_Vertical
J2: CPU Control; PinSocket_1x05_P2.54mm_Vertical
J3: Ext Clock; PinSocket_1x03_P2.54mm_Vertical
JP1: Jumper; PinHeader_1x02_P2.54mm_Vertical
R1, R2: 1k; R_Axial_DIN0207_L6.3mm_D2.5mm_P7.62mm_Horizontal
R3: 10k; R_Axial_DIN0207_L6.3mm_D2.5mm_P7.62mm_Horizontal
SW1: SW_Push; SW_PUSH_6mm
U1: 74LS393; DIP-14_W7.62mm
X1: Osc 16MHz; Oscillator_DIP-14

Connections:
/Clock: J2.2, J3.1, JP1.2
GND: C1.2, J2.5, J3.3, R2.2, SW1.1, U1.2 (MR), U1.7 (GND), U1.12 (MR), X1.7 (GND)
unnamed: D1.1 (K), D2.2 (A), J2.3
unnamed: D1.2 (A), R1.2
unnamed: D2.1 (K), R2.1
unnamed: J1.1, U1.3 (Q0)
unnamed: J1.3, U1.4 (Q1)
unnamed: J1.5, U1.5 (Q2)
unnamed: J1.7, U1.6 (Q3), U1.13 (CP)
unnamed: J1.9, U1.11 (Q0)
unnamed: J1.2, J1.4, J1.6, J1.8, J1.10, J1.12, J1.14, J1.16, JP1.1
unnamed: J1.11, U1.10 (Q1)
unnamed: J1.13, U1.9 (Q2)
unnamed: J1.15, U1.8 (Q3)
unnamed: J2.1, R3.2, SW1.2
unnamed: U1.1 (CP), X1.8 (OUT)
VCC: C1.1, J2.4, J3.2, R1.1, R3.1, U1.14 (VCC), X1.1 (EN), X1.14 (Vcc)

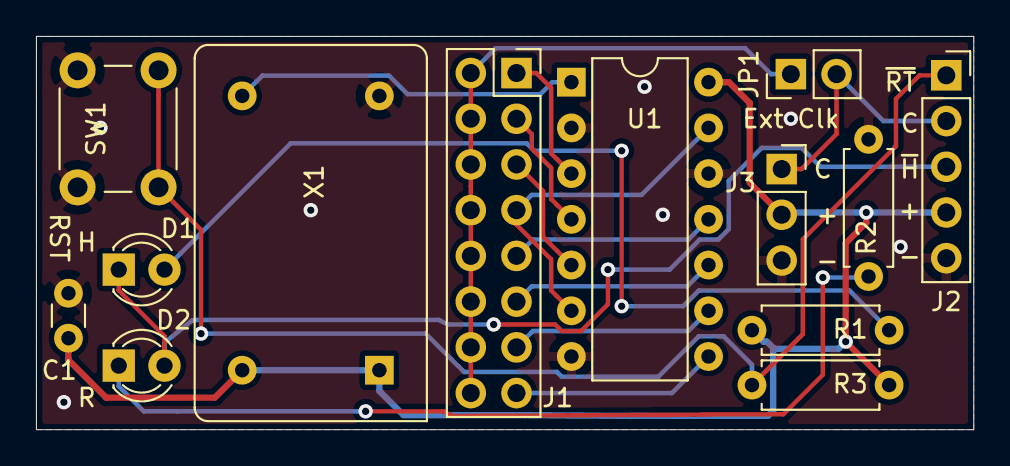
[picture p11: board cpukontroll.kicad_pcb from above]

Board: 2 copper layers, 52.1 x 21.8 mm, 13 parts (0 on the bottom side), 17 nets.

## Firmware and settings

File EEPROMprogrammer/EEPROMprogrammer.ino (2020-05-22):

//NOT CHECKED!
#define SHIFT_ADRESS 2
#define SHIFT_CLK 4
#define ADRESS_CLK 3
#define WE_ 13
#define RE_ 14
#define BRQ_ 15
#define BAK_ 16
#define AOE_ 17
#define D0 5 //datapins 5 to 12

const unsigned int start_adress = 0x0000;
const byte data[] = { 0xAA, 0x01, 0x02, 0x03 };

void shiftAdress(unsigned int adress) {
    digitalWrite(ADRESS_CLK, LOW);
    shiftOut(SHIFT_ADRESS, SHIFT_CLK, MSBFIRST, adress >> 8);
    shiftOut(SHIFT_ADRESS, SHIFT_CLK, MSBFIRST, adress);
    delayMicroseconds(1);
    digitalWrite(ADRESS_CLK, HIGH);  
}

void writeData() {
  digitalWrite(RE_, HIGH);
  delayMicroseconds(1);
  for (int p=0; p<8; p++) {
    pinMode(D0+p, OUTPUT);
  }
  Serial.println("Writing data");
  Serial.print(start_adress, HEX);
  Serial.print('\t');
  for (int i = 0; i < sizeof(data); i++) {
    shiftAdress(start_adress+i);
    byte d=data[i];
    Serial.print(d,HEX);
    Serial.print('\t');
    delayMicroseconds(1);
    for (int p = 0; p <8; p += 1) {
      digitalWrite(p+D0, d & 1);
      d = d >> 1;
    }
    delay(10);
    digitalWrite(WE_, LOW);
    delayMicroseconds(200);
    digitalWrite(WE_, HIGH);
    if (i%16 ==0 && i>0) {
      Serial.print('\n');
      Serial.print(start_adress+i,HEX);
      Serial.print('\t');
    }
  }
  Serial.println("\nEnd of data");
  for (int p=0; p<8; p++) {
    pinMode(D0+p, INPUT);
  }
  delayMicroseconds(1);  
}

void readData(int read_length) {
  digitalWrite(WE_, HIGH);
  for (int p=0; p<8; p++) {
    pinMode(D0+p, INPUT);
  }
  Serial.print("Reading data");
  for (int i = 0; i < read_length; i++) {
    shiftAdress(start_adress+i);
    delayMicroseconds(1);
    digitalWrite(RE_, LOW);
    delayMicroseconds(1);
    byte dat=0;
    for (int p = D0+7; p >= D0; p -= 1) {
      dat = (dat << 1) + digitalRead(p);
    }
    digitalWrite(RE_, HIGH);
    if (i%16 == 0) {
      Serial.print("\n");
      Serial.print(start_adress+i, HEX);
    }
    Serial.print(" ");
    Serial.print(dat, HEX);
  } 
  Serial.print("\nEnd of data"); 
}

void setup() {
  Serial.begin(57600);
  pinMode(SHIFT_ADRESS, OUTPUT);
  pinMode(SHIFT_CLK, OUTPUT);
  pinMode(ADRESS_CLK, OUTPUT);
  pinMode(WE_, OUTPUT);
  pinMode(RE_, OUTPUT);
  pinMode(BRQ_, OUTPUT);
  pinMode(BAK_, INPUT);
  pinMode(AOE_, OUTPUT);
  for (int p=0; p<8; p++) {
    pinMode(D0+p, INPUT);
  }
  digitalWrite(WE_, HIGH);
  digitalWrite(RE_, HIGH);
  digitalWrite(AOE_, HIGH);
  digitalWrite(BRQ_, LOW);
  digitalWrite(ADRESS_CLK, LOW);
  delay(200);
  while (digitalRead(BAK_)) delay(200);
  digitalWrite(AOE_, LOW);
  runOnce();
}
void runOnce() {
  delay(200);
  writeData();
  delay(200);
  readData(32); 
}

void loop() {
}

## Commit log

2019-10-31 Display start
    [display.kicad_pcb, display.sch]
2019-10-31 More Display work
    [Dator.kicad_pcb, display.sch]
2019-11-02 lib cache added and display schema
    [cpukontroll.sch, display.sch]
2019-11-02 display schema first version ready
    [display.sch]
2019-11-02 display tracks drawn
    [display.kicad_pcb]
2019-11-03 display pcb first version ready
    [display.kicad_pcb, display.sch]
2019-11-09 started tangentbord
    [display.kicad_pcb, tangentbord.kicad_pcb, tangentbord.sch]
2019-11-10 Tangentbord pcb v1
    [tangentbord.kicad_pcb, tangentbord.sch]
2019-12-13 EEPROMprogrammerare pcb
    [Programmer.kicad_pcb, Programmer.sch]
2020-02-19 pcb filer
    [Dator-B_Cu.gbr, Dator-B_Mask.gbr, Dator-B_SilkS.gbr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]
2020-04-08 Frame for dator pcb
    [platta.FCStd, platta.stl]
2020-04-09 Frame updated dim
    [platta.FCStd, platta.stl]
2020-05-22 In situ programming hw
    [Programmer.kicad_pcb, Programmer.sch]
2020-05-23 Pull up AOE
    [Programmer.kicad_pcb, Programmer.sch]
